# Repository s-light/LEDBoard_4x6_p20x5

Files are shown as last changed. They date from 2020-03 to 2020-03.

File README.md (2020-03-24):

<!--lint disable maximum-line-length-->
<!--lint disable list-item-spacing-->
<!--lint disable list-item-indent-->

# LEDBoard_4x6_p20x5

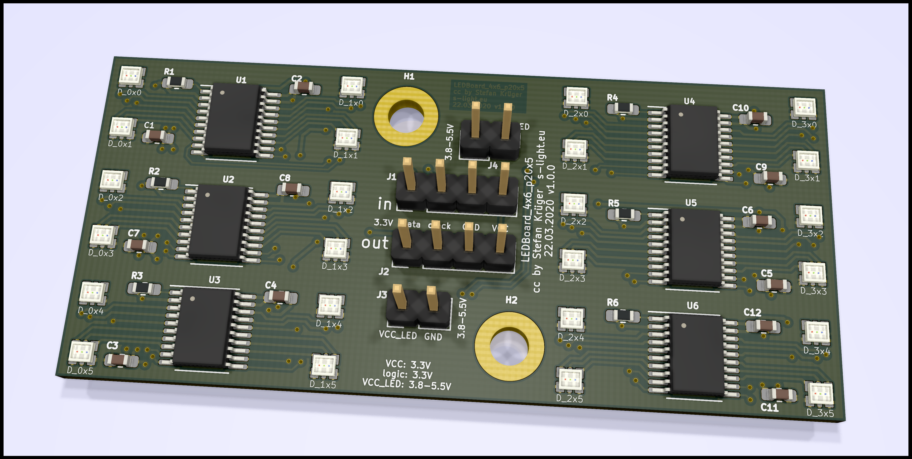
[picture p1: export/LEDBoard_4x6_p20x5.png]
LED-Board 3d rendering

LED-Board 3d rendering

- LEDBoard with 4x6 LEDs
- pixel pitch: 20mm x 5mm
- LED: [Rohm MSL0402RGB](https://www.rohm.com/datasheet/MSL0402RGBU) (1.8x1.6x0.5mm RGB)
- Driver: [TI TLC5971](http://www.ti.com/product/TLC5971) (16bit dimming, constant current driver)

<br>

<br>

<br>

---

<!-- TOC depthFrom:1 depthTo:6 withLinks:1 updateOnSave:1 orderedList:0 -->

- [LEDBoard_4x6_p20x5](#ledboard4x6p20x5)
	- [Project-Status](#project-status)
	- [Technical Information](#technical-information)
		- [mapping](#mapping)
			- [c++ / arduino](#c-arduino)
		- [HW](#hw)
		- [controlling](#controlling)
	- [License](#license)

<!-- /TOC -->

---
<br>

## Project-Status
WIP
- [x] design schematics
- [x] layout pcb
- [ ] order pcbs
- [ ] order parts
- [ ] solder boards
- [ ] test
- [ ] update documentation

## Technical Information
there are groups of 4 LEDs that are controlled by one TLC5971.  
every controller chip has 12 ConstantCurrent outputs.
so every LED is controllable individual.

### mapping
you need to create a mapping to linearize the order:  

TODO: test & check if this table is correct

| | 0 | 1 | 2 | 3 |
| :---- | :--- | :--- | :--- | :--- |
| **0** | IC1 LED1 | IC1 LED2 | IC4 LED1 | IC4 LED2 |
| **1** | IC1 LED3 | IC1 LED4 | IC4 LED3 | IC4 LED4 |
| **2** | IC2 LED1 | IC2 LED2 | IC5 LED1 | IC5 LED2 |
| **3** | IC2 LED3 | IC2 LED4 | IC5 LED3 | IC5 LED4 |
| **4** | IC3 LED1 | IC3 LED2 | IC6 LED1 | IC6 LED2 |
| **5** | IC3 LED3 | IC3 LED4 | IC6 LED3 | IC6 LED4 |

#### c++ / arduino
```c++
const uint8_t channel_position_map[4][4] = {
    { 0,  1, 12, 13},
    { 2,  3, 14, 15},
    { 4,  5, 16, 17},
    { 6,  7, 18, 19},
    { 8,  9, 20, 21},
    {10, 11, 22, 23},
};
```

<!-- #### CircuitPython
```python
channel_position_map[4][4] = {
    { 0,  1, 12, 13},
    { 2,  3, 14, 15},
    { 4,  5, 16, 17},
    { 6,  7, 18, 19},
    { 8,  9, 20, 21},
    {10, 11, 22, 23},
};
``` -->

### HW
- PCB size: ?x?x1,6mm
- pixel-pitch: 20x5mm
- 3.8V..5.5V
- <= ??A (maximum)

### controlling
for arduino you can use [ulrichstern/Tlc59711](https://github.com/ulrichstern/Tlc59711)

for other things have a look at [LEDBoard_4x4_16bit](https://github.com/s-light/LEDBoard_4x4_16bit#controlling)

---

## License
<!-- license info -->
<p>
<a rel="license" href="http://creativecommons.org/licenses/by/4.0/">
    <img alt="Creative Commons License" style="border-width:0"
        src="https://i.creativecommons.org/l/by/4.0/88x31.png" />
</a>
<br />
<span xmlns:dct="http://purl.org/dc/terms/" property="dct:title">
    all files in LEDBoard_4x6_p20x5
</span> by
<a xmlns:cc="http://creativecommons.org/ns#"
        href="https://github.com/s-light/LEDBoard_4x6_p20x5"
        property="cc:attributionName"
        rel="cc:attributionURL">
    Stefan Krüger (s-light)
</a>
are licensed under a<br/>
<a rel="license" href="http://creativecommons.org/licenses/by/4.0/">
    Creative Commons Attribution 4.0 International License
</a>.
</p>

all software parts/files are licensed under [MIT](LICENSE).

<!-- license info end -->

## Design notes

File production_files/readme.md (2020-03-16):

folder content is ignored by git.
save pcb-pool 'watchUrPCB' images and production gerber files here.

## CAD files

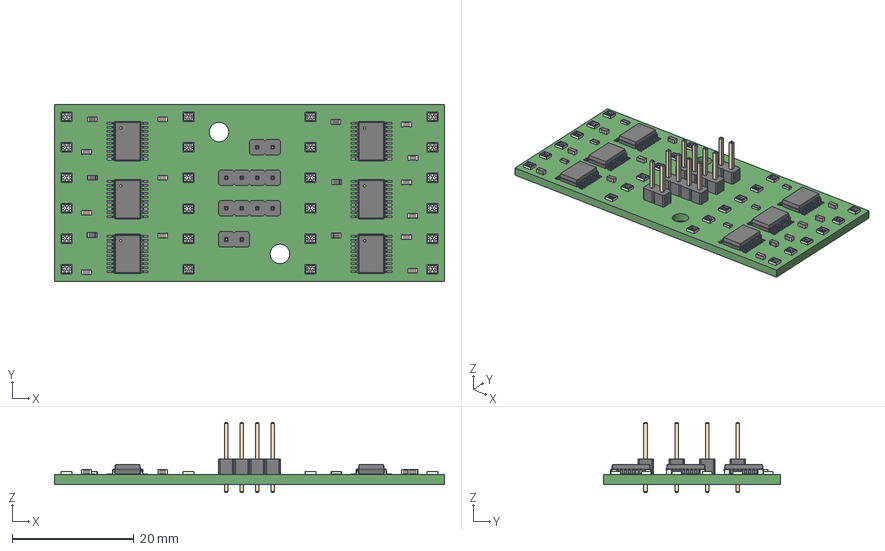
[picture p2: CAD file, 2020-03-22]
export/LEDBoard_4x6_p20x5.step
64.0 x 29.0 x 11.5 mm

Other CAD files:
export/LEDBoard_4x6_p20x5.FCStd

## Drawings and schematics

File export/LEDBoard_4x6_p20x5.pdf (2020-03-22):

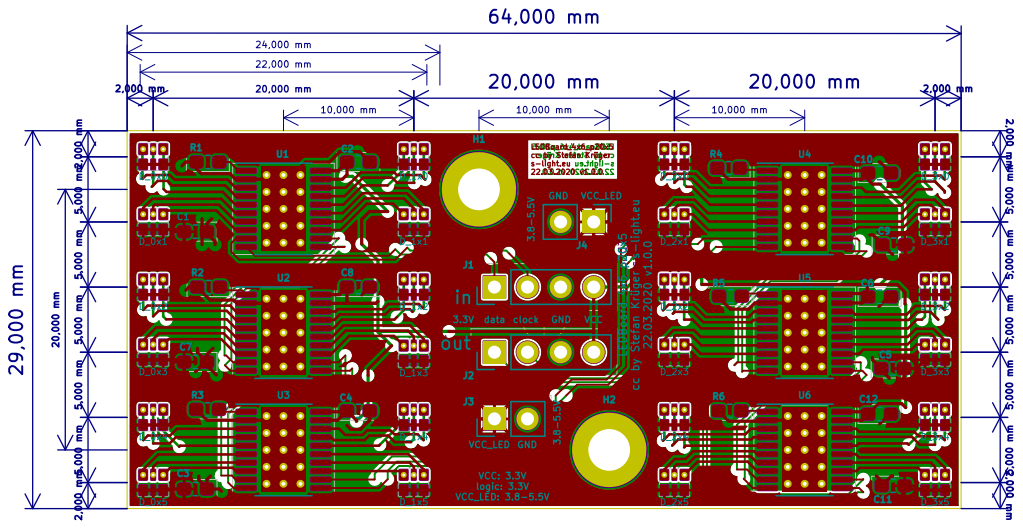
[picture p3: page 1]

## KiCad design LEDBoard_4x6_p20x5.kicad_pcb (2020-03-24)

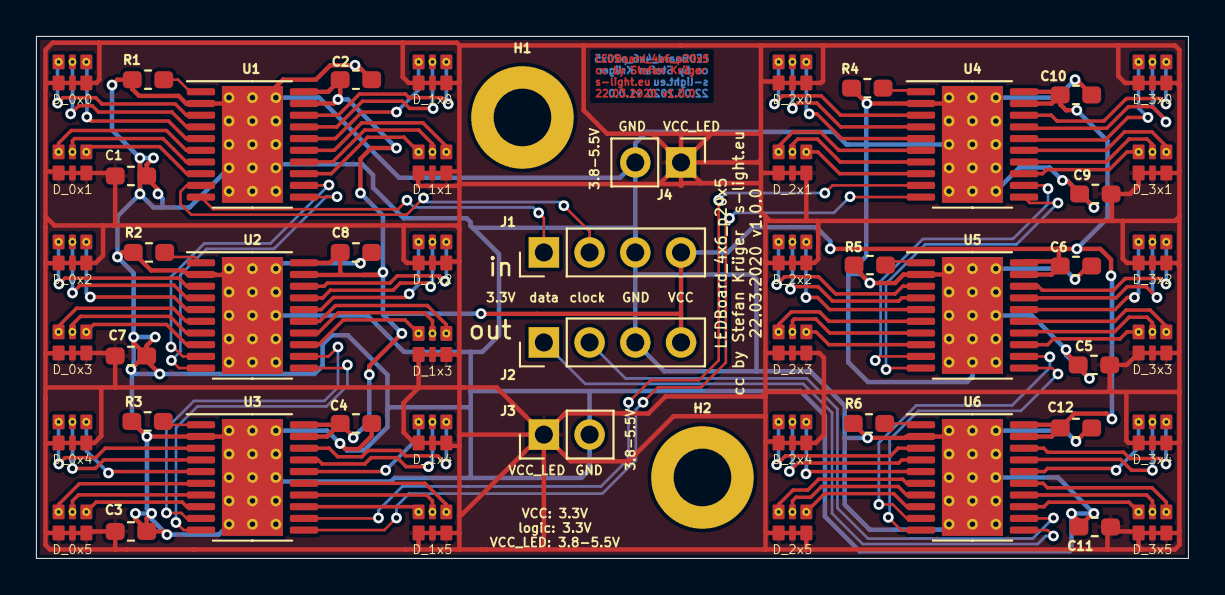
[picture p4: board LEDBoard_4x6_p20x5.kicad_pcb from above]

Board: 2 copper layers, 64.0 x 29.0 mm, 54 parts (0 on the bottom side), 95 nets.

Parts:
C1, C3, C5, C7, C9, C11: 10uF 6.3V; C_0603_1608Metric_Pad1.05x0.95mm_HandSolder
C2, C4, C6, C8, C10, C12: 100n; C_0603_1608Metric_Pad1.05x0.95mm_HandSolder
D_0x0, D_0x1, D_0x2, D_0x3, D_0x4, D_0x5, D_1x0, D_1x1, D_1x2, D_1x3, D_1x4, D_1x5, D_2x0, D_2x1, D_2x2, D_2x3, D_2x4, D_2x5, D_3x0, D_3x1, D_3x2, D_3x3, D_3x4, D_3x5: LED_RGB; LED_RGB_0706_1816Metric_ROHM_ThermalVias
H1, H2: MH_M3; MountingHole_3.2mm_M3_ISO7380_Pad
J1: signal_in; PinHeader_1x04_P2.54mm_Vertical
J2: signal_out; PinHeader_1x04_P2.54mm_Vertical
J3: power_in; PinHeader_1x02_P2.54mm_Vertical
J4: power_out; PinHeader_1x02_P2.54mm_Vertical
R1, R2, R3, R4, R5, R6: 2k7 0.1%; R_0603_1608Metric_Pad1.05x0.95mm_HandSolder
U1, U2, U3, U4, U5, U6: TLC5971PWP; HTSSOP-20-1EP_4.4x6.5mm_P0.65mm_EP3.4x6.5mm_Mask2.75x3.43mm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

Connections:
/clock_1-2: U1.12, U2.9
/clock_2-3: U2.12, U3.9
/clock_3-4: U3.12, U4.9
/clock_4-5: U4.12, U5.9
/clock_5-6: U5.12, U6.9
/clock_in: J1.2, U1.9
/clock_out: J2.2, U6.12
/data_1-2: U1.11, U2.10
/data_2-3: U2.11, U3.10
/data_3-4: U3.11, U4.10
/data_4-5: U4.11, U5.10
/data_5-6: U5.11, U6.10
/data_in: J1.1, U1.10
/data_out: J2.1, U6.11
/led_0x0_b: D_0x0.3, U1.5
/led_0x0_g: D_0x0.2, U1.4
/led_0x0_r: D_0x0.1, U1.3
/led_0x1_b: D_0x1.3, U1.8
/led_0x1_g: D_0x1.2, U1.7
/led_0x1_r: D_0x1.1, U1.6
/led_0x2_b: D_0x2.3, U2.5
/led_0x2_g: D_0x2.2, U2.4
/led_0x2_r: D_0x2.1, U2.3
/led_0x3_b: D_0x3.3, U2.8
/led_0x3_g: D_0x3.2, U2.7
/led_0x3_r: D_0x3.1, U2.6
/led_0x4_b: D_0x4.3, U3.5
/led_0x4_g: D_0x4.2, U3.4
/led_0x4_r: D_0x4.1, U3.3
/led_0x5_b: D_0x5.3, U3.8
/led_0x5_g: D_0x5.2, U3.7
/led_0x5_r: D_0x5.1, U3.6
/led_1x0_b: D_1x0.3, U1.18
/led_1x0_g: D_1x0.2, U1.17
/led_1x0_r: D_1x0.1, U1.16
/led_1x1_b: D_1x1.3, U1.15
/led_1x1_g: D_1x1.2, U1.14
/led_1x1_r: D_1x1.1, U1.13
/led_1x2_b: D_1x2.3, U2.18
/led_1x2_g: D_1x2.2, U2.17
/led_1x2_r: D_1x2.1, U2.16
/led_1x3_b: D_1x3.3, U2.15
/led_1x3_g: D_1x3.2, U2.14
/led_1x3_r: D_1x3.1, U2.13
/led_1x4_b: D_1x4.3, U3.18
/led_1x4_g: D_1x4.2, U3.17
/led_1x4_r: D_1x4.1, U3.16
/led_1x5_b: D_1x5.3, U3.15
/led_1x5_g: D_1x5.2, U3.14
/led_1x5_r: D_1x5.1, U3.13
/led_2x0_b: D_2x0.3, U4.5
/led_2x0_g: D_2x0.2, U4.4
/led_2x0_r: D_2x0.1, U4.3
/led_2x1_b: D_2x1.3, U4.8
/led_2x1_g: D_2x1.2, U4.7
/led_2x1_r: D_2x1.1, U4.6
/led_2x2_b: D_2x2.3, U5.5
/led_2x2_g: D_2x2.2, U5.4
/led_2x2_r: D_2x2.1, U5.3
/led_2x3_b: D_2x3.3, U5.8
/led_2x3_g: D_2x3.2, U5.7
/led_2x3_r: D_2x3.1, U5.6
/led_2x4_b: D_2x4.3, U6.5
/led_2x4_g: D_2x4.2, U6.4
/led_2x4_r: D_2x4.1, U6.3
/led_2x5_b: D_2x5.3, U6.8
/led_2x5_g: D_2x5.2, U6.7
/led_2x5_r: D_2x5.1, U6.6
/led_3x0_b: D_3x0.3, U4.18
/led_3x0_g: D_3x0.2, U4.17
/led_3x0_r: D_3x0.1, U4.16
/led_3x1_b: D_3x1.3, U4.15
/led_3x1_g: D_3x1.2, U4.14
/led_3x1_r: D_3x1.1, U4.13
/led_3x2_b: D_3x2.3, U5.18
/led_3x2_g: D_3x2.2, U5.17
/led_3x2_r: D_3x2.1, U5.16
/led_3x3_b: D_3x3.3, U5.15
/led_3x3_g: D_3x3.2, U5.14
/led_3x3_r: D_3x3.1, U5.13
/led_3x4_b: D_3x4.3, U6.18
/led_3x4_g: D_3x4.2, U6.17
/led_3x4_r: D_3x4.1, U6.16
/led_3x5_b: D_3x5.3, U6.15
/led_3x5_g: D_3x5.2, U6.14
/led_3x5_r: D_3x5.1, U6.13
GND: C1.2, C2.2, C3.2, C4.2, C5.2, C6.2, C7.2, C8.2, C9.2, C10.2, C11.2, C12.2, H1.1, H2.1, J1.3, J2.3, J3.2, J4.2, R1.2, R2.2, R3.2, R4.2, R5.2, R6.2, U1.2, U1.21, U2.2, U2.21, U3.2, U3.21, U4.2, U4.21, U5.2, U5.21, U6.2, U6.21
unnamed: R1.1, U1.1
unnamed: R2.1, U2.1
unnamed: R3.1, U3.1
unnamed: R4.1, U4.1
unnamed: R5.1, U5.1
unnamed: R6.1, U6.1
VCC: C2.1, C4.1, C6.1, C8.1, C10.1, C12.1, J1.4, J2.4, U1.19, U1.20, U2.19, U2.20, U3.19, U3.20, U4.19, U4.20, U5.19, U5.20, U6.19, U6.20
VCC_LED: C1.1, C3.1, C5.1, C7.1, C9.1, C11.1, D_0x0.4, D_0x0.5, D_0x0.6, D_0x1.4, D_0x1.5, D_0x1.6, D_0x2.4, D_0x2.5, D_0x2.6, D_0x3.4, D_0x3.5, D_0x3.6, D_0x4.4, D_0x4.5, D_0x4.6, D_0x5.4, D_0x5.5, D_0x5.6, D_1x0.4, D_1x0.5, D_1x0.6, D_1x1.4, D_1x1.5, D_1x1.6, D_1x2.4, D_1x2.5, D_1x2.6, D_1x3.4, D_1x3.5, D_1x3.6, D_1x4.4, D_1x4.5, D_1x4.6, D_1x5.4, D_1x5.5, D_1x5.6, D_2x0.4, D_2x0.5, D_2x0.6, D_2x1.4, D_2x1.5, D_2x1.6, D_2x2.4, D_2x2.5, D_2x2.6, D_2x3.4, D_2x3.5, D_2x3.6, D_2x4.4, D_2x4.5, D_2x4.6, D_2x5.4, D_2x5.5, D_2x5.6, D_3x0.4, D_3x0.5, D_3x0.6, D_3x1.4, D_3x1.5, D_3x1.6, D_3x2.4, D_3x2.5, D_3x2.6, D_3x3.4, D_3x3.5, D_3x3.6, D_3x4.4, D_3x4.5, D_3x4.6, D_3x5.4, D_3x5.5, D_3x5.6, J3.1, J4.1

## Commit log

2020-03-16 prepare KiCad project
    [LEDBoard_4x6_p20x5.kicad_pcb, LEDBoard_4x6_p20x5.sch]
2020-03-16 start schematic
    [LEDBoard_4x6_p20x5.sch]
2020-03-17 schematic partly done
    [LEDBoard_4x6_p20x5.sch]
2020-03-18 fixed schematic ordering + placed parts
    [LEDBoard_4x6_p20x5.kicad_pcb, LEDBoard_4x6_p20x5.sch]
2020-03-20 pcb mostly done
    [LEDBoard_4x6_p20x5.kicad_pcb]
2020-03-21 added possible heatsink location
    [LEDBoard_4x6_p20x5.kicad_pcb]
2020-03-21 pcb done
    [LEDBoard_4x6_p20x5.kicad_pcb]
2020-03-22 export done
    [LEDBoard_4x6_p20x5.kicad_pcb, LEDBoard_4x6_p20x5.step]
2020-03-22 exported gerber
    [LEDBoard_4x6_p20x5-B_Cu.gbr, LEDBoard_4x6_p20x5-B_Mask.gbr, LEDBoard_4x6_p20x5-B_Paste.gbr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]
2020-03-24 remove passmark + reexport
    [LEDBoard_4x6_p20x5-B_Cu.gbr, LEDBoard_4x6_p20x5-B_Mask.gbr, LEDBoard_4x6_p20x5-B_Paste.gbr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]
2020-03-25 export: added Excellon drill files
    [LEDBoard_4x6_p20x5.FCStd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]

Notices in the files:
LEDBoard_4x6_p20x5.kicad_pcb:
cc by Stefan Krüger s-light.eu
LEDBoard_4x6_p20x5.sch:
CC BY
